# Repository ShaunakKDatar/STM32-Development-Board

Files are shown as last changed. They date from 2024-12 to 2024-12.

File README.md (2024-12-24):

# STM32F1038TX Development Board

## Overview
This STM32F1038TX development board is designed for embedded system developers and hobbyists. It features essential peripherals and interfaces for rapid prototyping and testing. The board is powered by an AMS1117 voltage regulator, ensuring a stable 3.3V supply from USB input.

## Features
- **Microcontroller:** STM32F1038TX (ARM Cortex-M3)
- **Clock:** 16MHz External Crystal Oscillator
- **Voltage Regulator:** AMS1117 (USB to 3.3V conversion)
- **Connectors:**
   - UART
   - SWD (Serial Wire Debug)
   - I2C
- **Switches:**
   - User SPDT Switch
   - NRST (Reset) Switch
   - BOOT0 Switch
- **User LED:** 1 programmable user LED

## Pin Configuration
- **UART Pins:** TX (PA9), RX (PA10)
- **I2C Pins:** SDA (PB7), SCL (PB6)
- **SWD Pins:** SWCLK (PA14), SWDIO (PA13)
- **User LED:** PA5
- **SPDT Switch:** PA0
- **NRST Switch:** NRST Pin
- **BOOT0 Switch:** BOOT0 Pin

## Power Supply
- **Input Voltage:** 5V via USB
- **Regulated Voltage:** 3.3V via AMS1117

## Schematic
Screenshot 2024-12-24 at 9 17 16 AM

## Routing 
Screenshot 2024-12-24 at 9 16 29 AM 
Screenshot 2024-12-24 at 9 16 38 AM

## Programming and Debugging
1. Use an SWD programmer (e.g., ST-Link V2) for flashing firmware.
2. Ensure BOOT0 is set to 0 for normal operation, 1 for DFU/bootloader mode.
3. Use UART for serial communication.

## Getting Started
1. Connect the board to your computer via USB.
2. Flash firmware using SWD.
3. Use UART for debugging and monitoring.
4. Toggle the User LED and interact with the SPDT switch.

## Safety Precautions
- Ensure correct power supply voltage.
- Avoid short circuits on the board.
- Handle components with care.

## Resources
- [STM32F103 Reference Manual](https://www.st.com/resource/en/reference_manual/cd00171190.pdf)
- [STM32CubeIDE](https://www.st.com/en/development-tools/stm32cubeide.html)

## License
This project is open-source under the MIT License.

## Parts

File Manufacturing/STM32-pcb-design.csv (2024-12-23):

Reference | Value | Datasheet | Footprint | Qty | DNP
C1,C2,C3,C4,C9,C14,C15 | 100n | ~ | Capacitor_SMD:C_0402_1005Metric | 7
C5 | 10u | ~ | Capacitor_SMD:C_0603_1608Metric | 1
C6 | 10n | ~ | Capacitor_SMD:C_0402_1005Metric | 1
C7,C8 | 1u | ~ | Capacitor_SMD:C_0402_1005Metric | 2
C10,C11 | 10p | ~ | Capacitor_SMD:C_0402_1005Metric | 2
C12,C13 | 22u | ~ | Capacitor_SMD:C_0603_1608Metric | 2
D1,D2 | RED | ~ | LED_SMD:LED_0603_1608Metric | 2
FB1 | FerriteBead | ~ | Inductor_SMD:L_0603_1608Metric | 1
J1 | USB_B_Micro | ~ | Connector_USB:USB_Micro-B_Wuerth_629105150521 | 1
J2,J3,J4 | Conn_01x04_Pin | ~ | Connector_PinHeader_2.54mm:PinHeader_1x04_P2.54mm_Vertical | 3
R1,R2 | 10k | ~ | Resistor_SMD:R_0402_1005Metric | 2
R3,R4,R5,R6,R7 | 1k5 | ~ | Resistor_SMD:R_0402_1005Metric | 5
SW1,SW2,SW3 | SW_SPDT | ~ | Button_Switch_SMD:SW_SPDT_PCM12 | 3
U1 | STM32F103C8Tx | https://www.st.com/resource/en/datasheet/stm32f103c8.pdf | Package_QFP:LQFP-48_7x7mm_P0.5mm | 1
U2 | AMS1117-3.3 | http://www.advanced-monolithic.com/pdf/ds1117.pdf | Package_TO_SOT_SMD:SOT-223-3_TabPin2 | 1
Y1 | 16MHz | ~ | Crystal:Crystal_SMD_3225-4Pin_3.2x2.5mm | 1

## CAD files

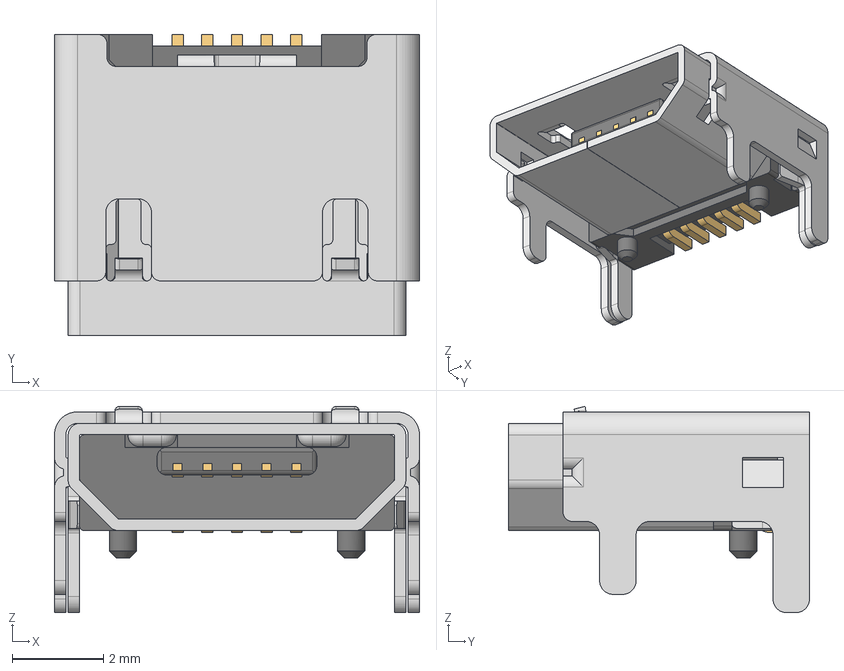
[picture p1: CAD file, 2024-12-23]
629105150521 (rev1).stp
8.00 x 6.60 x 4.52 mm
629105150521_Housing
629105150521_Pin1 x 4
629105150521_Pin2
629105150521_Shielding2
629105150521_Shielding

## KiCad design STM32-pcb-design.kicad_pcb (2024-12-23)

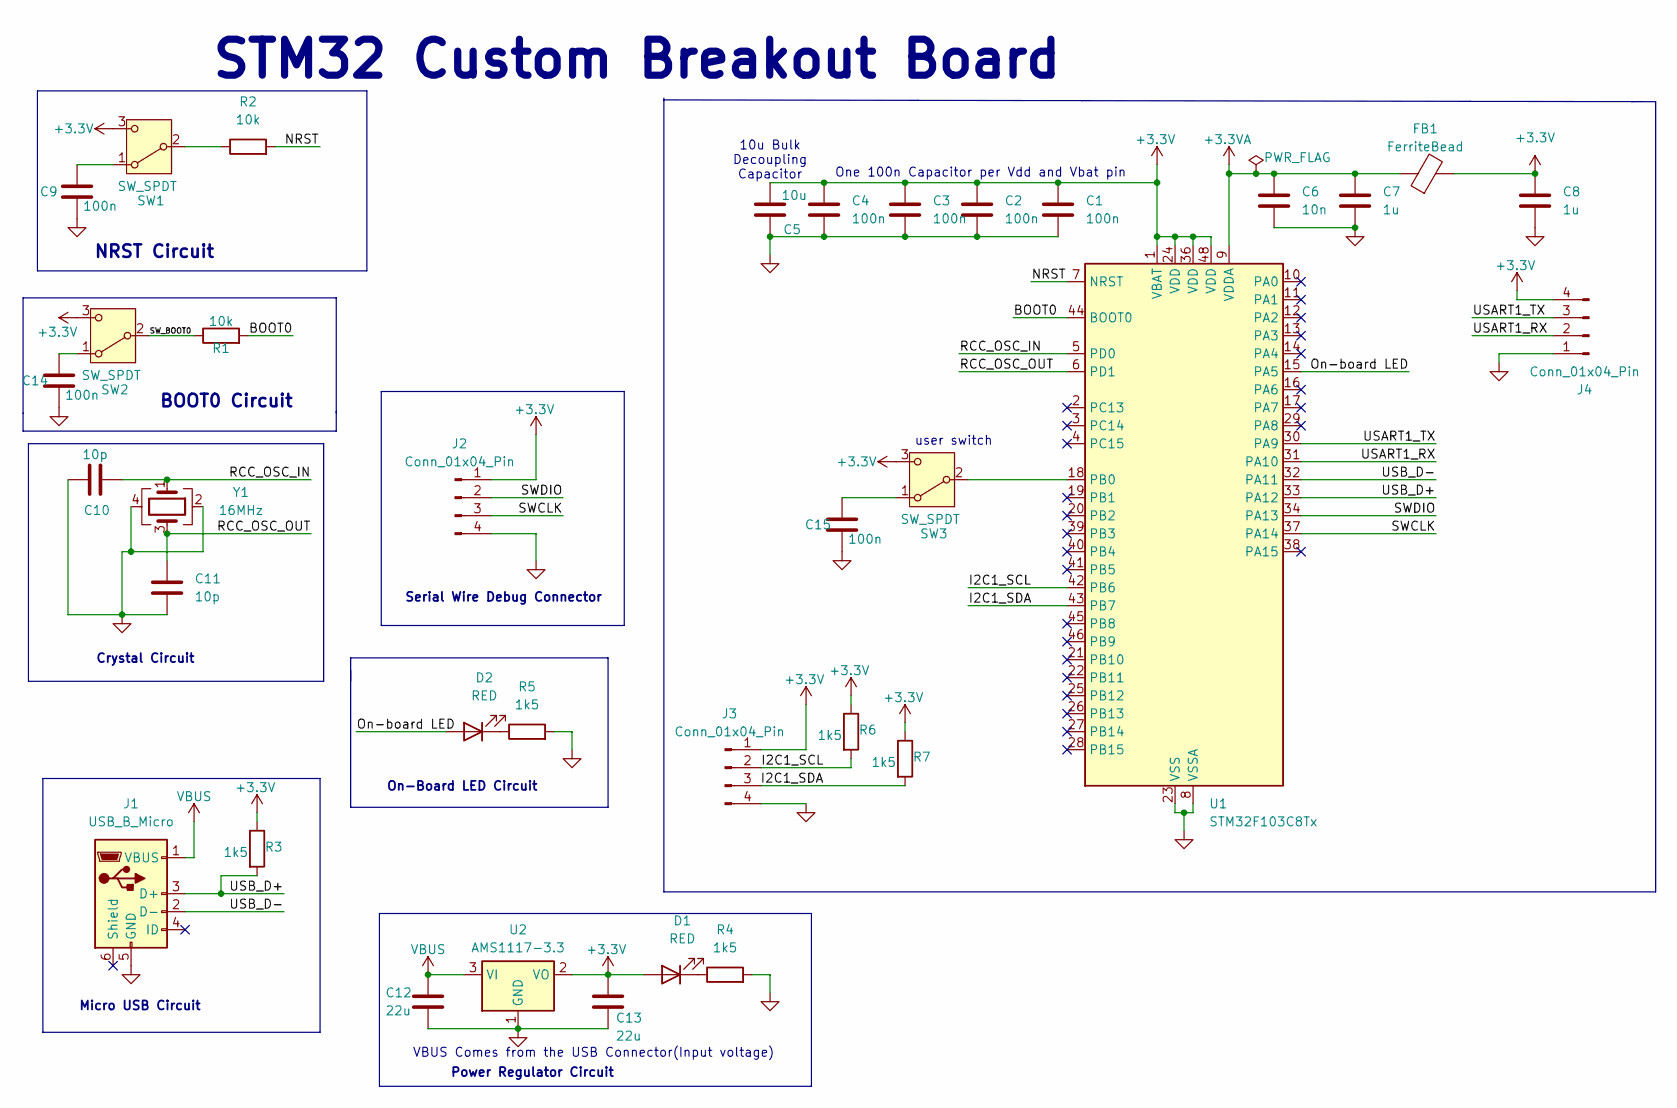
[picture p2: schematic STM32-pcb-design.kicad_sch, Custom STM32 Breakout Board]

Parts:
C1, C2, C3, C4, C9, C14, C15: 100n; C_0402_1005Metric
C5: 10u; C_0603_1608Metric
C6: 10n; C_0402_1005Metric
C7, C8: 1u; C_0402_1005Metric
C10, C11: 10p; C_0402_1005Metric
C12, C13: 22u; C_0603_1608Metric
D1, D2: RED; LED_0603_1608Metric
FB1: FerriteBead; L_0603_1608Metric
J1: USB_B_Micro; USB_Micro-B_Wuerth_629105150521
J2, J3, J4: Conn_01x04_Pin; PinHeader_1x04_P2.54mm_Vertical
R1, R2: 10k; R_0402_1005Metric
R3, R4, R5, R6, R7: 1k5; R_0402_1005Metric
SW1, SW2, SW3: SW_SPDT; SW_SPDT_PCM12
U1: STM32F103C8Tx; LQFP-48_7x7mm_P0.5mm
U2: AMS1117-3.3; SOT-223-3_TabPin2
Y1: 16MHz; Crystal_SMD_3225-4Pin_3.2x2.5mm

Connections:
+3.3V: C1.1, C2.1, C3.1, C4.1, C5.1, C8.1, C13.1, D1.2 (A), FB1.2, J2.1, J3.1, J4.4, R3.1, R6.1, R7.1, SW1.3 (C), SW2.3 (C), SW3.3 (C), U1.1 (VBAT), U1.24 (VDD), U1.36 (VDD), U1.48 (VDD), U2.2 (VO)
+3.3VA: C6.1, C7.1, FB1.1, U1.9 (VDDA)
/BOOT0: R1.2, U1.44 (BOOT0)
/I2C1_SCL: J3.2, R6.2, U1.42 (PB6)
/I2C1_SDA: J3.3, R7.2, U1.43 (PB7)
/NRST: R2.2, U1.7 (NRST)
/On-board LED: D2.2 (A), U1.15 (PA5)
/RCC_OSC_IN: C10.2, U1.5 (PD0), Y1.1
/RCC_OSC_OUT: C11.1, U1.6 (PD1), Y1.3
/SWCLK: J2.3, U1.37 (PA14)
/SWDIO: J2.2, U1.34 (PA13)
/SW_BOOT0: R1.1, SW2.2 (B)
/USART1_RX: J4.2, U1.31 (PA10)
/USART1_TX: J4.3, U1.30 (PA9)
/USB_D+: J1.3 (D+), R3.2, U1.33 (PA12)
/USB_D-: J1.2 (D-), U1.32 (PA11)
GND: C1.2, C2.2, C3.2, C4.2, C5.2, C6.2, C7.2, C8.2, C9.2, C10.1, C11.2, C12.2, C13.2, C14.2, C15.2, J1.5 (GND), J2.4, J3.4, J4.1, R4.2, R5.2, U1.8 (VSSA), U1.23 (VSS), U1.35 (VSS), U1.47 (VSS), U2.1 (GND), Y1.2, Y1.4
unnamed: D1.1 (K), R4.1
unnamed: D2.1 (K), R5.1
unnamed: C9.1, SW1.1 (A)
unnamed: R2.1, SW1.2 (B)
unnamed: C14.1, SW2.1 (A)
unnamed: C15.1, SW3.1 (A)
unnamed: SW3.2 (B), U1.18 (PB0)
VBUS: C12.1, J1.1 (VBUS), U2.3 (VI)

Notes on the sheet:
On-Board LED Circuit
10u Bulk Decoupling Capacitor
BOOT0 Circuit
Power Regulator Circuit
Crystal Circuit
One 100n Capacitor per Vdd and Vbat pin
Micro USB Circuit
Serial Wire Debug Connector
STM32 Custom Breakout Board
NRST Circuit
VBUS Comes from the USB Connector(Input voltage)
user switch

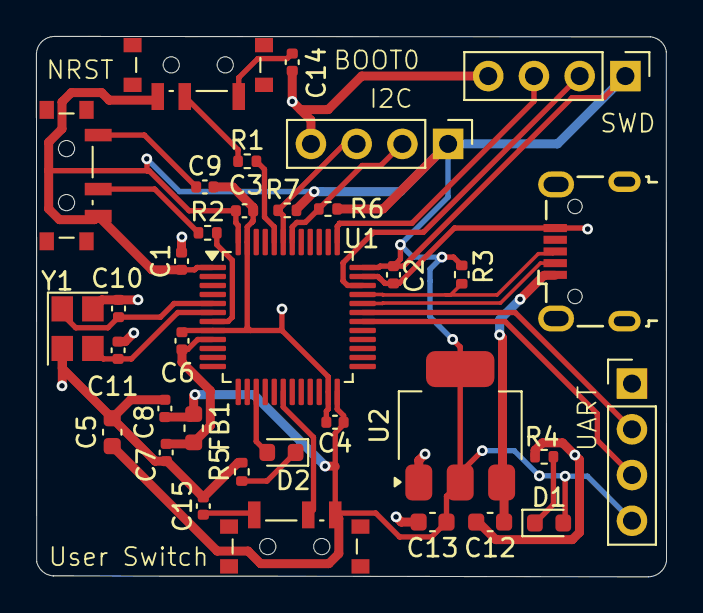
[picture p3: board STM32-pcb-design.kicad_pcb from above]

Board: 2 copper layers, 35.0 x 30.0 mm, 35 parts (0 on the bottom side), 25 nets.

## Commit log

2024-12-24 Edited Text in Schematic
    [STM32-pcb-design.kicad_sch]
2024-12-24 Adds Schematic Pictures to Readme
